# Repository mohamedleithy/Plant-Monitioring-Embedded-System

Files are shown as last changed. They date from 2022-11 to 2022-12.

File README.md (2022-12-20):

# Plant-Monitioring-Embedded-System

## Table of contents

* [Introduction ](https://github.com/mohamedleithy/Plant-Monitioring-Embedded-System#-introduction)
* [Background and Motivation](https://github.com/mohamedleithy/Plant-Monitioring-Embedded-System#Background-and-Motivation)
* [Problem Statement](https://github.com/mohamedleithy/Plant-Monitioring-Embedded-System#problem-statement)
* [Solution](https://github.com/mohamedleithy/Plant-Monitioring-Embedded-System#solution)
* [Features](https://github.com/mohamedleithy/Plant-Monitioring-Embedded-System#features)
* [Scale of the project](https://github.com/mohamedleithy/Plant-Monitioring-Embedded-System#scale-of-the-project)
* [Architecture](https://github.com/mohamedleithy/Plant-Monitioring-Embedded-System#architecture)
* [Iterations](https://github.com/mohamedleithy/Plant-Monitioring-Embedded-System#Iterations)
* [Benefits](https://github.com/mohamedleithy/Plant-Monitioring-Embedded-System#benefits)
* [Dashboard](https://github.com/mohamedleithy/Plant-Monitioring-Embedded-System#dashboard)
* [Conclusion and Future Work](https://github.com/mohamedleithy/Plant-Monitioring-Embedded-System#Conclusion-and-Future-Work)
* [Demo video](https://github.com/mohamedleithy/Plant-Monitioring-Embedded-System#Demo-video)
* [Authors](https://github.com/mohamedleithy/Plant-Monitioring-Embedded-System#authors)
* [Limitations](https://github.com/mohamedleithy/Plant-Monitioring-Embedded-System#limitations)
* [Supervisor](https://github.com/mohamedleithy/Plant-Monitioring-Embedded-System#supervisor)

# Introduction

Plant monitoring is a fundamental component of agriculture industries since it allows for controlling the growth of plants for the best possible output. Automating the process of plant monitoring and managing the environmental factors will ease the complexity of such process and will influence the growth of the plant and, consequently, its output. In this proposal a plant monitoring system is presented to provide feedback for the user on a web app. The proposal includes a detailed description of the problem, architecture of the system and the components used.

# Background and Motivation

After skimming through the past projects, we found a past project that used sensors to record the temperature,humidty and soil mositure. We then decided we can improve on this project by actuating on these sensor readings in negative feedback loop. By doing so, we would provide a given plant with the optimial needed conditions (soil mositure) and automate the process of watering. 

# Problem Statement

We are addressing two problems:

* The water waste introduced by the classical agricultural techniques.
* The high running cost of the agricultural sites workers.

# Solution

Designing an embedded system with a negative feedback loop to efficiently monitor and control agricultural sites. The system will monitor the environment by deploying sensors that keep track of the temperature, humidity, and soil moisture level, to regulate the soil water level using an electronically controlled water valve. An online dashboard will be integrated into the system to report updates on the agricultural site.

# Requirmenets and Features

* The user will be able to select his/her plant type through the web interface, and the soil moisture level is specified accordingly
* The system will be able to monitor the temperature and soil moisture level.
* The system will be able to control the water level in the soil.
* The system will be able to modify the soil moisture level, based on the temprature. 
* The system will be able to report updates on the environment to the user.

# Scale of the project

* The system will be able to monitor indoor plants on a small scale, prototype is made on two average sized plant pots.

# Architecture

## Software architecture design

For the STM board:
We designed our embedded system to used FreeRTOS to coordinate its different tasks. The use of FreeRTOS was essential to allow parallel execution of the tasks in a real-time fashion. Moreover, the use of interrupts opened the door for handling aperiodic tasks in the system, and data racing conditions were handled using semaphores. 

For the raspberry pi pico:
Here we used a multithreaded architecture to allow the blocking of synchronous receiving and sending of the server. The python _thread library was used to generate a couple of threads that separately handle the sockets operations and the UART communication with the STM board.

## Hardware architecture design

### Block Diagram

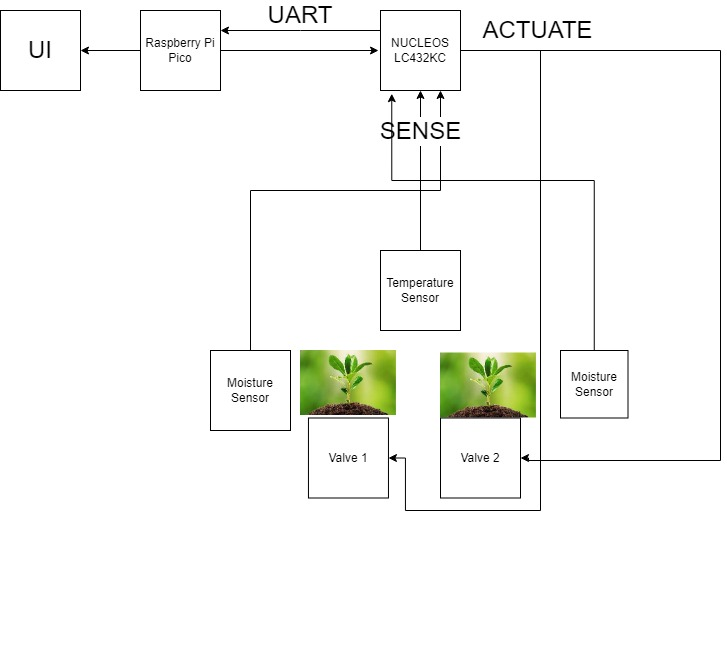
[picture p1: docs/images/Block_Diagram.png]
Block Diagram


### System Components

 * NUCLEO LC432K 
 * Raspberry pi pico 
 * Water Valve
 * Humidity Sensor
 * Temperature Sensor (DS3231 RTC)
 * Mositure Sensor 

#### NUCLEO LC432K
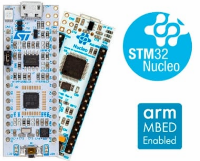
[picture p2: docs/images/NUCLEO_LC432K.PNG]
NUCLEO LC432K


#### Raspberry pi pico

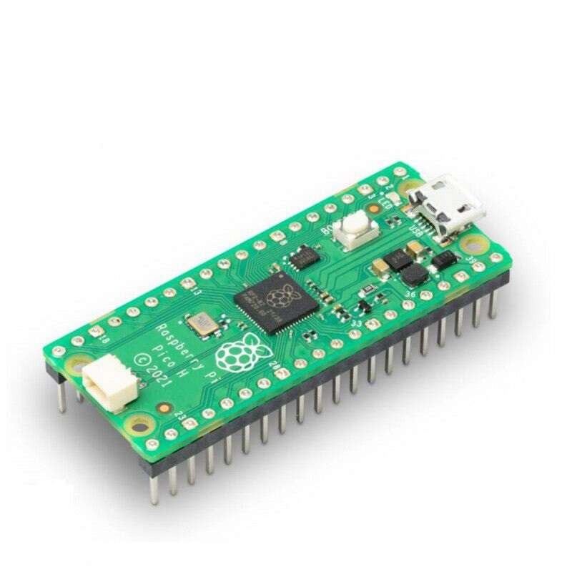
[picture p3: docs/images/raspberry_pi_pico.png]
ESP32


#### Water Valve

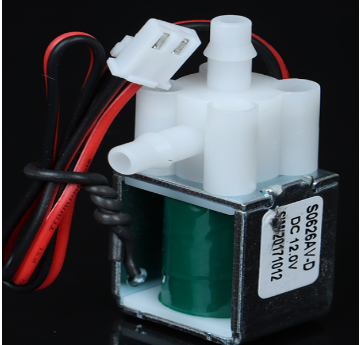
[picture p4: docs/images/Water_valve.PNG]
Water Valve


#### Relay

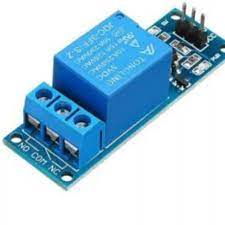
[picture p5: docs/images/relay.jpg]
Relay


#### Temperature Sensor

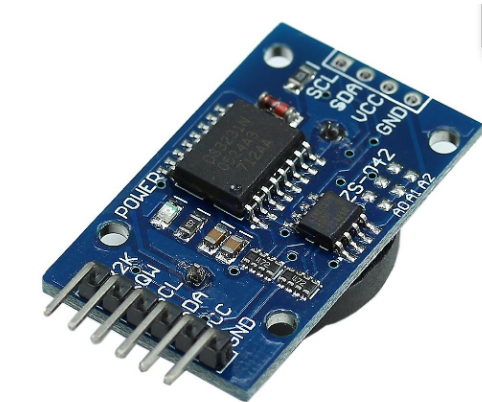
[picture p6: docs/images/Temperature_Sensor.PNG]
Temperature Sensor


#### Mositure Sensor

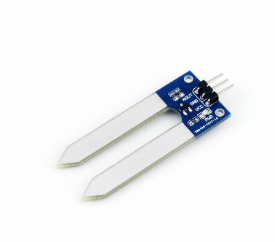
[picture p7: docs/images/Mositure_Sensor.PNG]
Mositure Sensor


### Connections:

* Deploy the STM board on the breadboard
* Deploy the Raspberry Pi Pico board on the breadboard
* Connect the two microcontrollers together via UART serial connection
* Connect the temprature sensor to the STM board using i2c synchronous connection
* Connect the 2 moisture sensor to the STM board using built in ADC on two seperate channels
* Connect each 12V supply to relay, connect relay output to the water valves
* Connect GPIO Pins to designated relay.

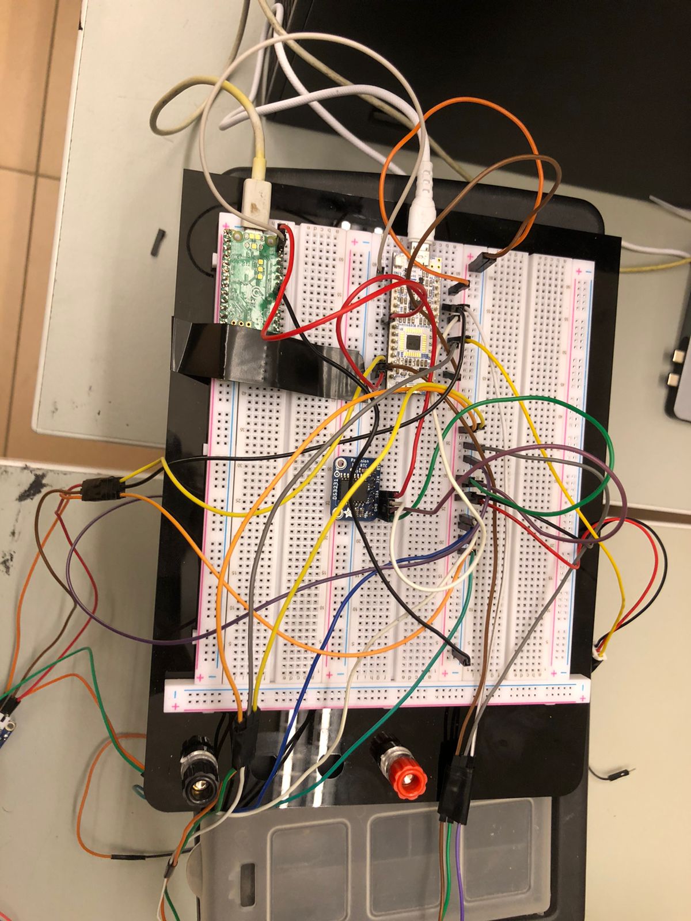
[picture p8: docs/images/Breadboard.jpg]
Breadboard Image


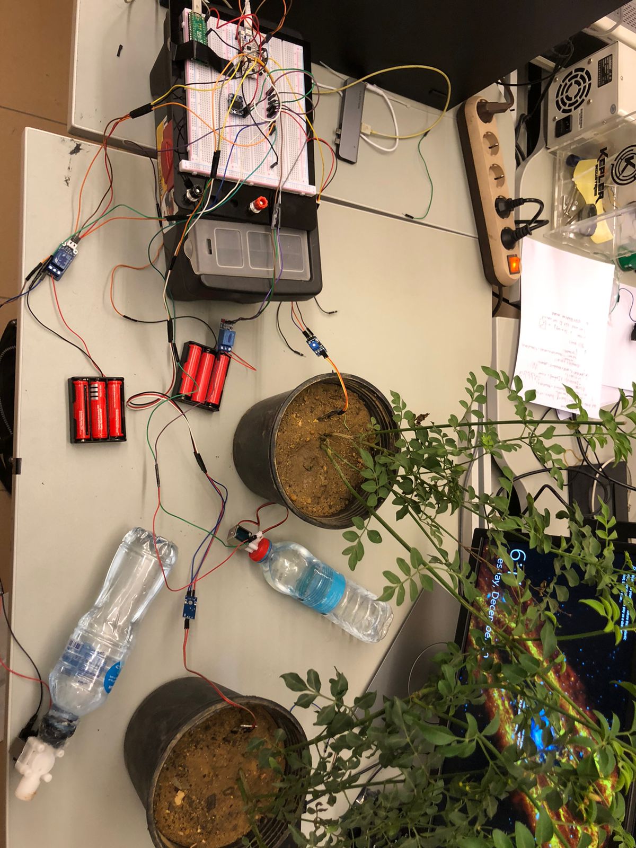
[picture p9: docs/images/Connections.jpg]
Connection Image


# Iterations

## First phase

Deployed STM and connected it to soil moisture and temperature sensor. 
Deployed ESP32 and connected it to humidty sensor.
Displayed Readings on Dashboard via Build-in Arudino APIs.

## Second phase

Removed ESP32 and deployed Raspberry Pico Pi.
Implemented User Interface via HTML, and intergrated front-end with Raspberry Pico Pi python back-end.

# Benefits

## Automation 
This embedded system would automate the process of watering plants, thus removing the need for human intervention on a daily basis resulting in error-free result in comparison to human labor, increasing consistency and reducing costs. 
## Real Time Display
With the use of the dashboard the user would be able to view the the real-time temperature, humidity and moisture directly through his/her phone/Desktop and get notified through telegram mobile application when any of the parameters approaches its threshold. 
## Set Optimal Conditions 
Given the monitored parameters, the system is able to water the plant and provide it with its optimal ecosystem that are predefined for a certain plant species to allow maximizing the plants’ growth and yield.

# Conlusion and Future Work

## Conclusion

it can be concluded that the system implemented successfully reads the soil moisture of plants and waters the plants accordingly. This system can be an effective solution for maintaining optimal soil moisture levels for plants, which is important for their health and growth. It can potentially save time and effort for gardeners and farmers by automating the watering process, and it may also help to conserve water by avoiding over-watering or under-watering. Overall, the implementation of this system appears to be a useful tool for the care and maintenance of plants.

## Future Work
* Adding additional sensors: The system could be enhanced with additional sensors to monitor other factors that may impact plant growth and health, such as light levels or nutrient levels in the soil.
* Expanding the watering capabilities: The system could be designed to support larger water bottles or to incorporate additional watering methods, such as a drip irrigation system or a spray system. This could allow the system to water plants more efficiently and effectively, particularly for larger grow areas or for plants with different watering needs.
* Improving the water bottle filling process: The system could be enhanced to make the process of filling the water bottles more efficient and convenient, potentially through the use of a water pump or other automation techniques.

# Dashboard

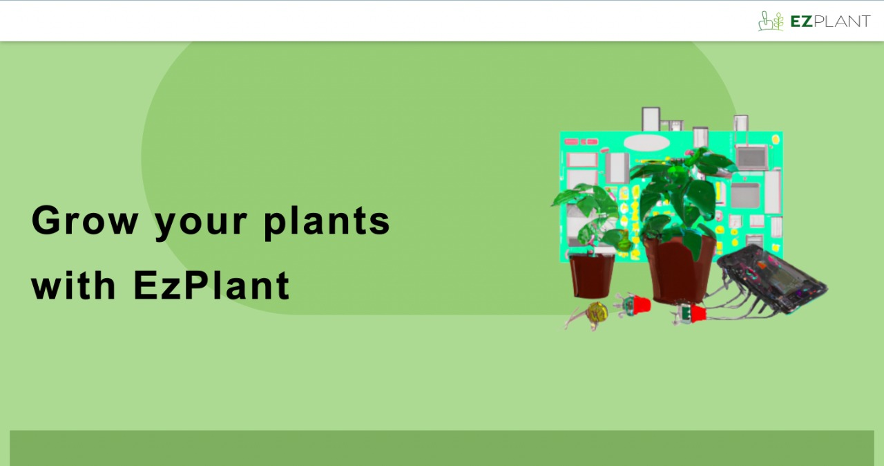
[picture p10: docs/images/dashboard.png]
Dashboard Image


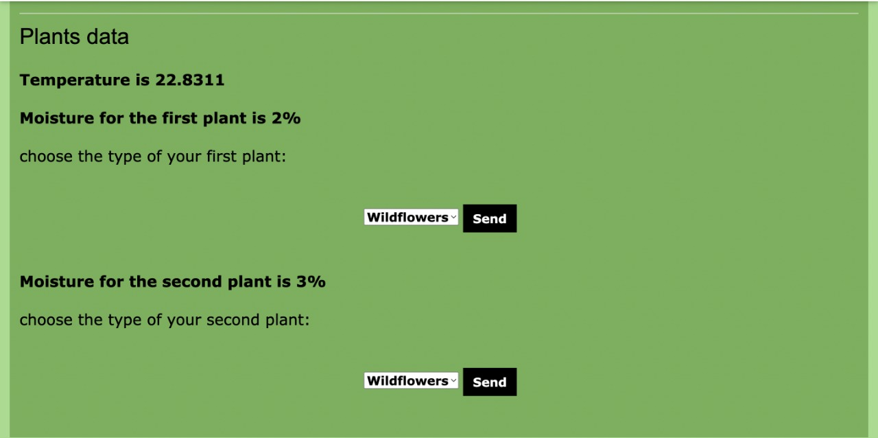
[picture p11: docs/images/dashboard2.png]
Dashboard Image 2


# Project Progress and Demo video

The system is now able to monitor the soil moisture level in two average sized plant pots, along with the temperature, and accordingly switch on/off the relay that controls the water solenoids attached to the water source. 

[Demo video link](https://drive.google.com/file/d/1defMuau6kGnW1_lsAHdz8Dkl8jO6r3im/view?usp=sharing)

# Limitations

* Our system handles no more than 6 pots.
* Distance limitation because the digital signal received by the ADC will catch a lot of noise
* The system is very expensive due to the cost of the components compared to the scale
* The system does not handle failures
    * Over-watering 
    * Does not troubleshoot technical issues in sensors
    * Force quit the system when a technical issue happens

# 3D Model of the system

* Base of the model
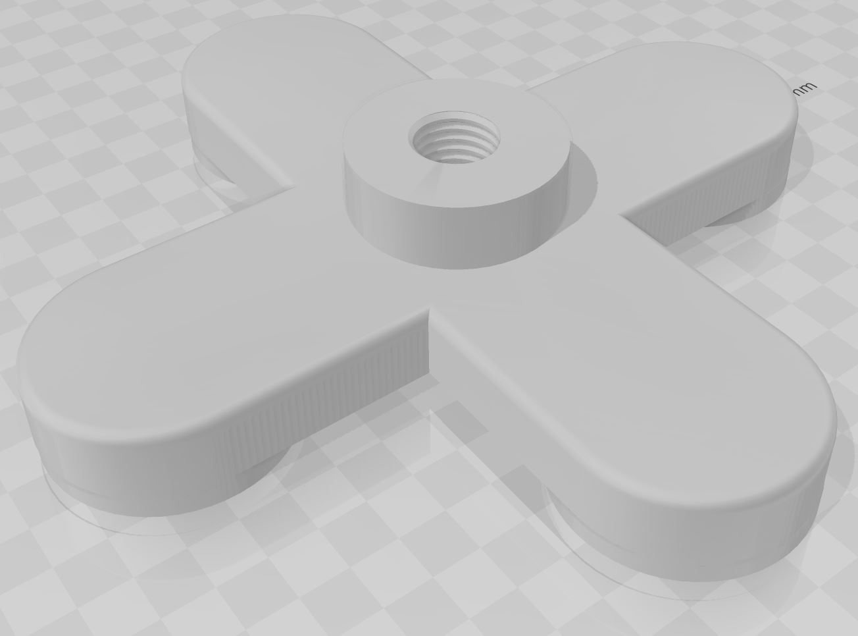
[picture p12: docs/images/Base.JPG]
Base of the model


* Cap of the model
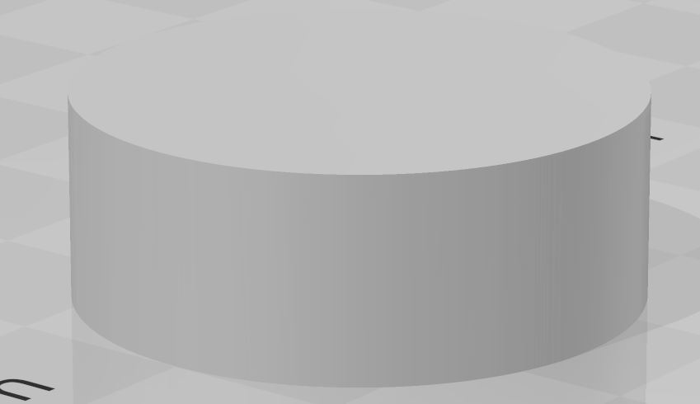
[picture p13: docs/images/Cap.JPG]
Cap of the model


* rod

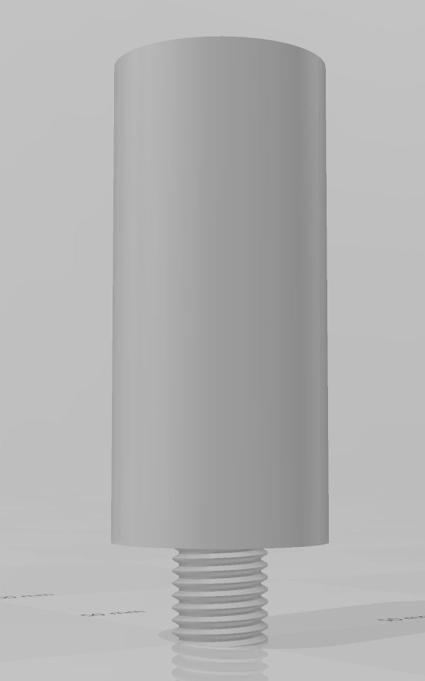
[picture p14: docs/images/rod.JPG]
rod


* Bottle

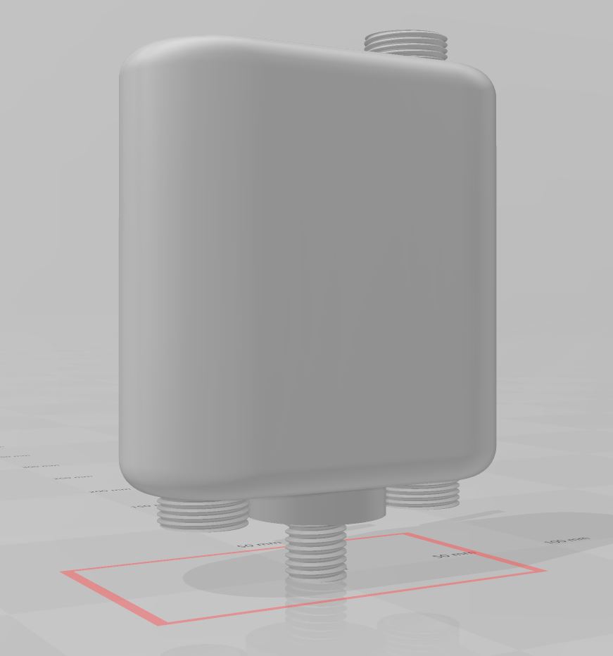
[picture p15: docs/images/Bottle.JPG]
Bottle


* Whole Model

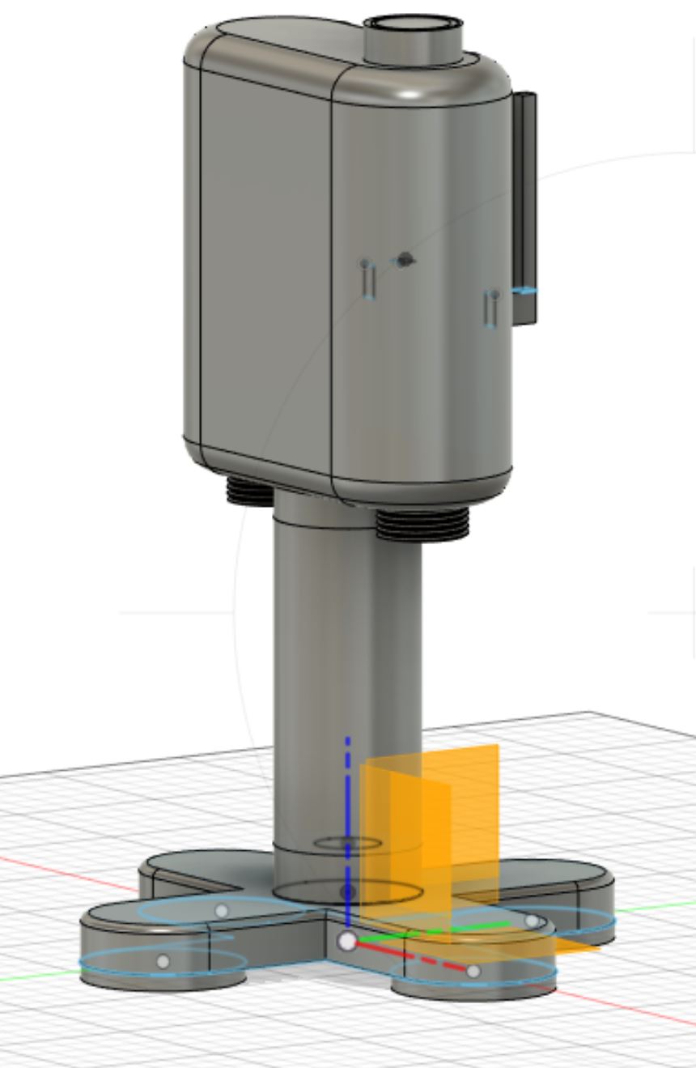
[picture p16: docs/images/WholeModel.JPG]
whole model


* Real image of the model (not printed properly)

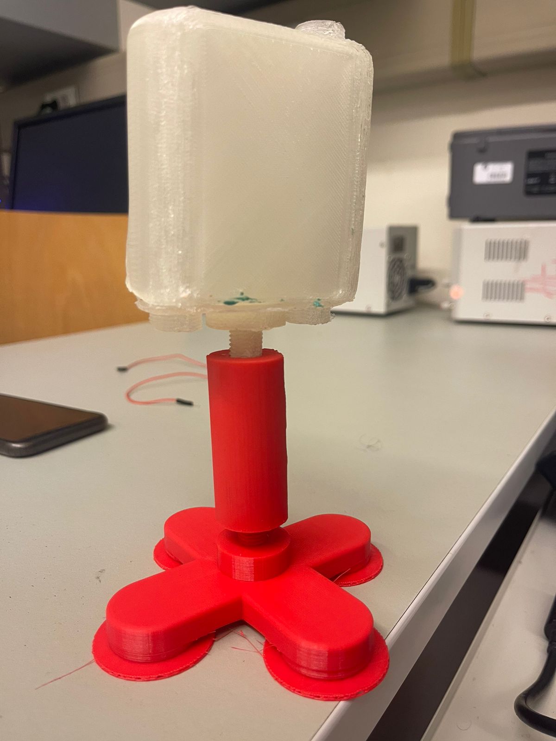
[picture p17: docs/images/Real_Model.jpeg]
Real model


* The model is basically consists of 4 parts:
    * The base
    * The cap
    * The rod
    * The bottle
* Each one of them is 3D printed and assembled together to form the final model. The base is assembled with the rods and the bottle is assembled with the cap and the rod. The bottle is then inserted into the base and the cap is inserted into the bottle.
The two opeenings in the bottom is responsible for the water to flow out of the bottle and the one opening in the top is responsible for the water to flow into the bottle for filling the bottle up.

# Authors

* [Mohamed Nasr](https://github.com/mnassr1658)
* [Mohamed Eleithy](https://github.com/mohamedleithy)
* [Abdullah Nashat](https://github.com/n42at)
* [Youssef Kandil](https://github.com/kanndil)

# Supervisor

* [Mohamed Shalan](https://github.com/shalan)

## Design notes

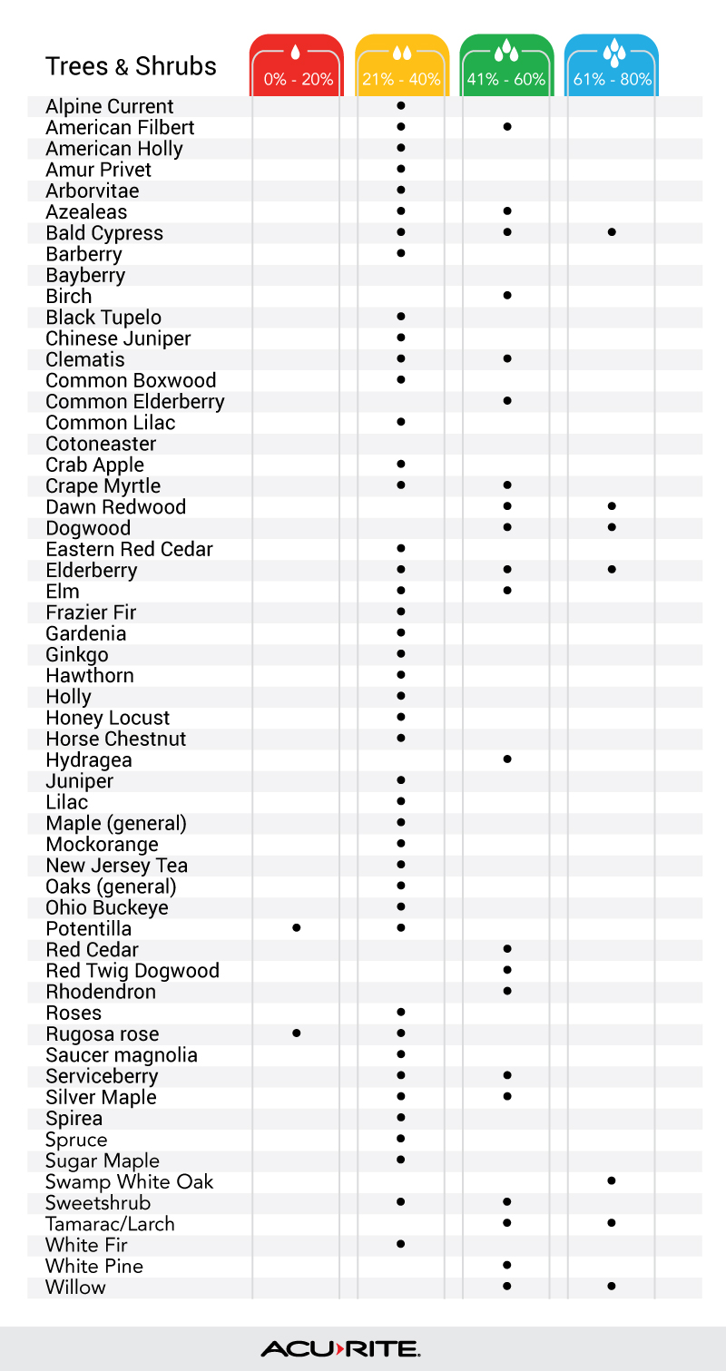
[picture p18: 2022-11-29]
docs/images/Trees&Shrubs.png

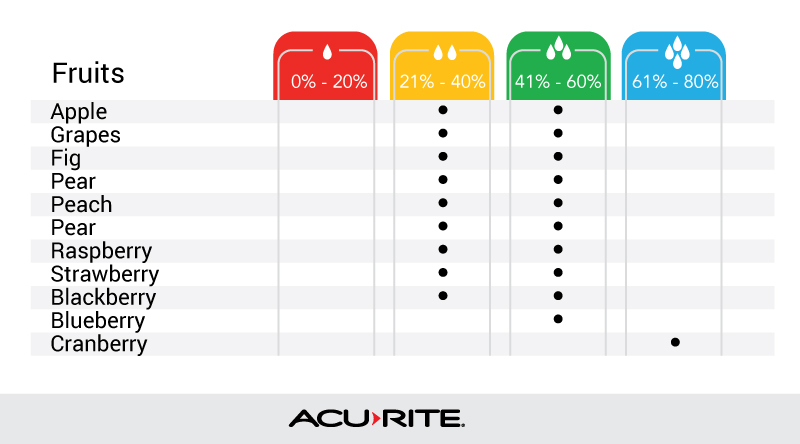
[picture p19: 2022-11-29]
docs/images/fruits.png

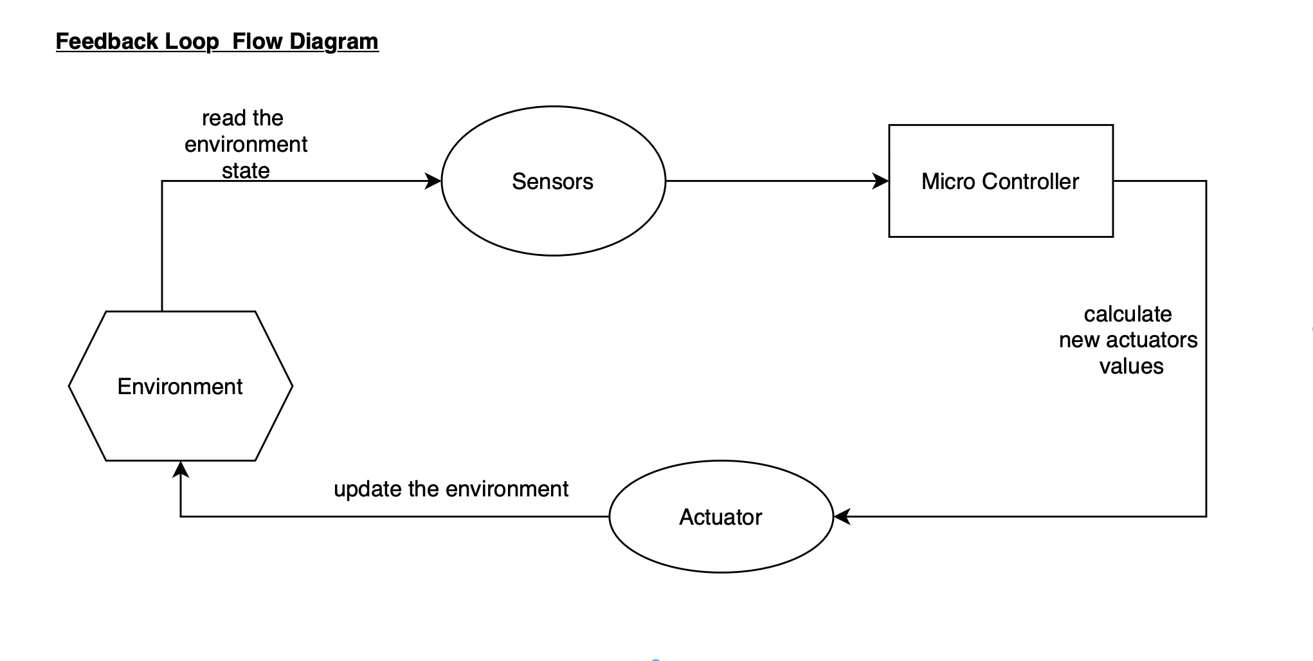
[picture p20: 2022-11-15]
docs/images/FeedbackLoop.png

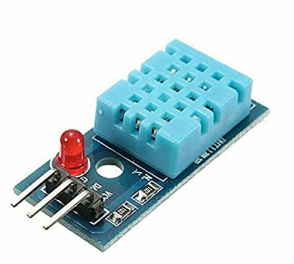
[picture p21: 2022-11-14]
docs/images/Humidity_Sensor.PNG

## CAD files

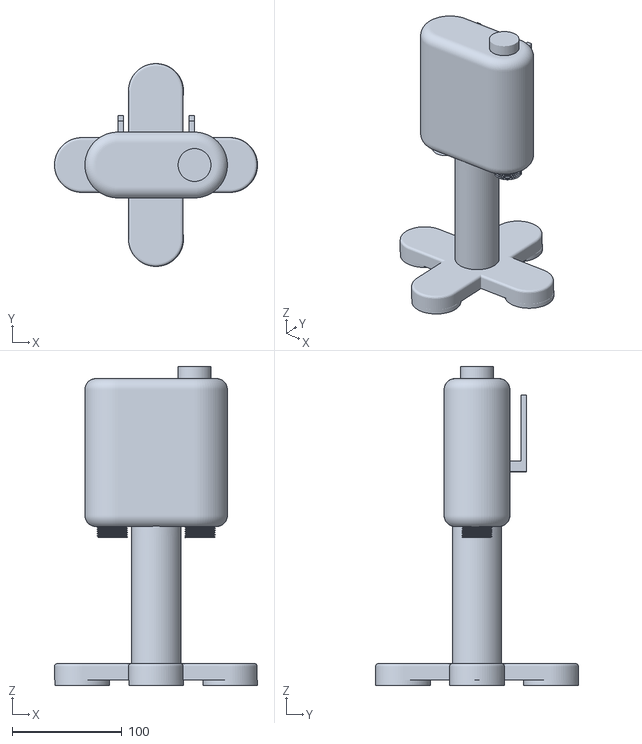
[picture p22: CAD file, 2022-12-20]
3DModeling/Whole Model.stl
185.3 x 185.0 x 291.0

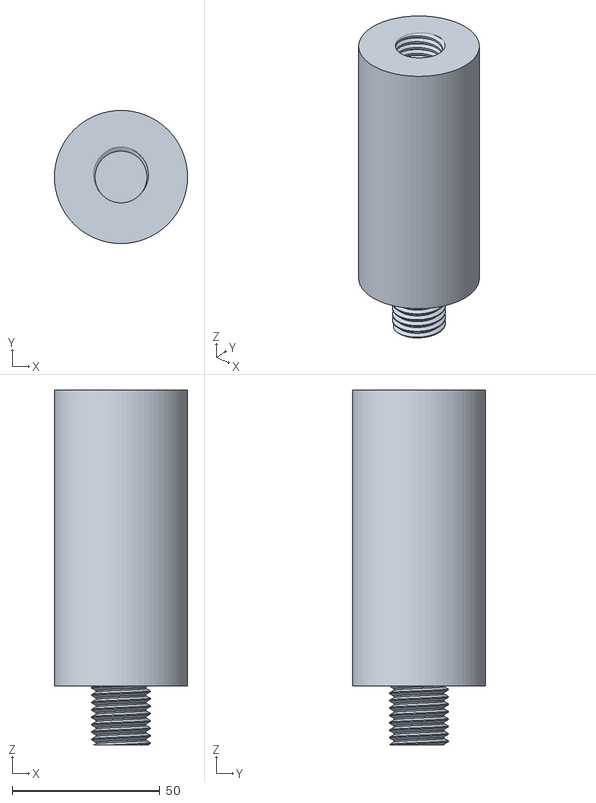
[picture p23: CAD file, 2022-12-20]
3DModeling/Rod.stl
45.0 x 45.0 x 120.0

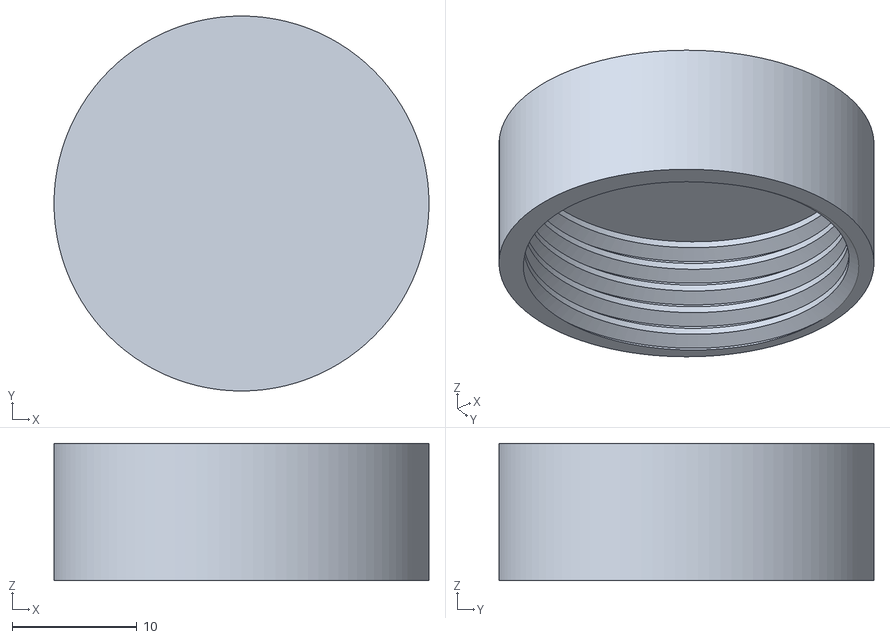
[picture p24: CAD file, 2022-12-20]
3DModeling/Cap.stl
30.0 x 30.0 x 11.0

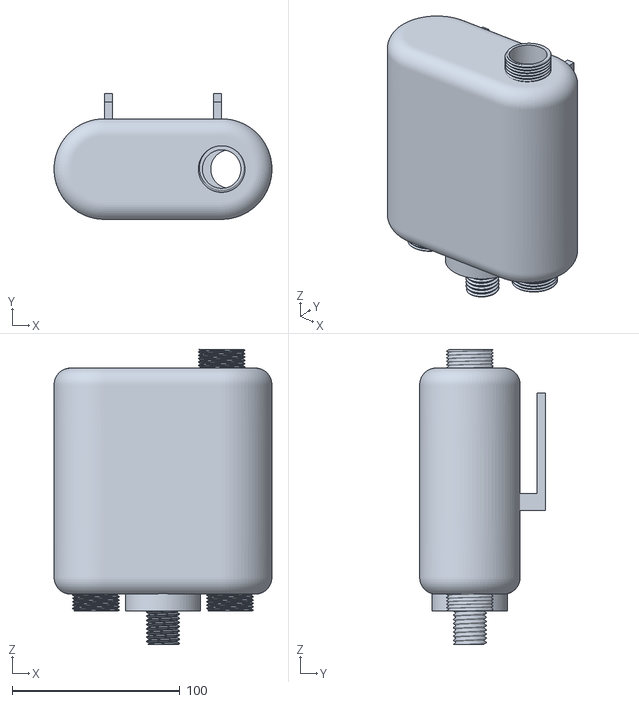
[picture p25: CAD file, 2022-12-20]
3DModeling/Bottle.stl
130.0 x 75.0 x 176.0

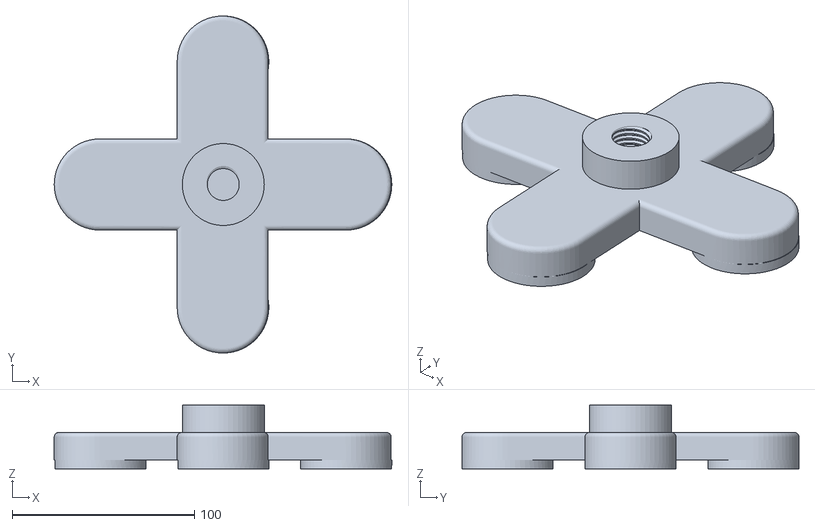
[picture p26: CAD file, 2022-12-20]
3DModeling/Base.stl
185.3 x 185.0 x 35.0

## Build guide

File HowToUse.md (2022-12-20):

# How to use 

## STM32 
* Check the pin configurations and connect the needed wires based on the connection section in the readme file and the CubeMX configuration project
* Build the source code using Keil software 
* Load to the STM MicroController

## Raspberry PI Pico
* Open the Thonny IDE to interface with the Raspberry PI pico 
* Open server.py on Thonny 
* Configure the WIFI SSID and Password 
* Load the code onto the MicroController

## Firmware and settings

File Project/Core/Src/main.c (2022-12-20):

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
/* Includes ------------------------------------------------------------------*/
#include "main.h"
#include "cmsis_os.h"

/* USER CODE BEGIN Includes */
#include <stdio.h>
#include "FreeRTOS.h"
#include "queue.h"
#include "task.h"
#include "semphr.h"
/* USER CODE END Includes */

/* USER CODE BEGIN PM */

extern float moisture_perc;
extern float moisture_perc2;
extern int adcflag;
/* USER CODE END PM */

ADC_HandleTypeDef hadc1;

I2C_HandleTypeDef hi2c3;

UART_HandleTypeDef huart1;
UART_HandleTypeDef huart2;

/* Definitions for defaultTask */
osThreadId_t defaultTaskHandle;
const osThreadAttr_t defaultTask_attributes = {
  .name = "defaultTask",
  .stack_size = 128 * 4,
  .priority = (osPriority_t) osPriorityNormal,
};
/* Definitions for SensorsTask */
osThreadId_t SensorsTaskHandle;
const osThreadAttr_t SensorsTask_attributes = {
  .name = "SensorsTask",
  .stack_size = 128 * 4,
  .priority = (osPriority_t) osPriorityLow,
};
/* Definitions for UartCommunicati */
osThreadId_t UartCommunicatiHandle;
const osThreadAttr_t UartCommunicati_attributes = {
  .name = "UartCommunicati",
  .stack_size = 128 * 4,
  .priority = (osPriority_t) osPriorityLow,
};
/* Definitions for Calculate */
osThreadId_t CalculateHandle;
const osThreadAttr_t Calculate_attributes = {
  .name = "Calculate",
  .stack_size = 128 * 4,
  .priority = (osPriority_t) osPriorityLow,
};
/* Definitions for Calculate2 */
osThreadId_t Calculate2Handle;
const osThreadAttr_t Calculate2_attributes = {
  .name = "Calculate2",
  .stack_size = 128 * 4,
  .priority = (osPriority_t) osPriorityLow,
};
/* Definitions for UartCom2 */
osThreadId_t UartCom2Handle;
const osThreadAttr_t UartCom2_attributes = {
  .name = "UartCom2",
  .stack_size = 128 * 4,
  .priority = (osPriority_t) osPriorityLow,
};
/* Definitions for myBinarySem01 */
osSemaphoreId_t myBinarySem01Handle;
const osSemaphoreAttr_t myBinarySem01_attributes = {
  .name = "myBinarySem01"
};
/* USER CODE BEGIN PV */


uint8_t ctlbuf[2],statbuf[2], tempupsend[1],tempdownsend[1], tempuprec[1],tempdownrec[1];
uint8_t tempvalue;
float tempfr, tempfinal;
uint8_t humidity,temp1; 
uint8_t uartBuf [100], uartBuf1 [100] = {0};
char uartBuf2[100] = {0}, uartBuf3[100] = {0}, uartBuf4[100] = {0};
float moistureLimit =60.0;
float moistureLimit2 =60.0;
uint8_t data[2] = {0};

/* USER CODE END PV */

void SystemClock_Config(void);
static void MX_GPIO_Init(void);
static void MX_USART2_UART_Init(void);
static void MX_ADC1_Init(void);
static void MX_I2C3_Init(void);
static void MX_USART1_UART_Init(void);
void StartDefaultTask(void *argument);
void StartTask02(void *argument);
void StartTask03(void *argument);
void StartTask04(void *argument);
void StartTask05(void *argument);
void StartTask06(void *argument);

/**
  * @brief  The application entry point.
  * @retval int
  */
int main(void)
{
  /* MCU Configuration--------------------------------------------------------*/

  /* Reset of all peripherals, Initializes the Flash interface and the Systick. */
  HAL_Init();

  /* Configure the system clock */
  SystemClock_Config();

  /* Initialize all configured peripherals */
  MX_GPIO_Init();
  MX_USART2_UART_Init();
  MX_ADC1_Init();
  MX_I2C3_Init();
  MX_USART1_UART_Init();
  /* USER CODE BEGIN 2 */
  __HAL_UART_ENABLE_IT(&huart1,UART_IT_RXNE);
  ctlbuf[0] = 0x0E;
	ctlbuf[1] = 0x3C;
 
  HAL_I2C_Master_Transmit(&hi2c3, 0xD0, ctlbuf, 2, 10);

	statbuf[0] = 0x0F;
	statbuf[1] = 0x88;
 
	HAL_I2C_Master_Transmit(&hi2c3, 0xD0, statbuf, 2, 10);
	// send to tempupper upperbyte register /*Integer Part*/
  tempupsend[0] = 0x11; // address of the register // reference page: DS page 15
  HAL_I2C_Master_Transmit(&hi2c3, 0xD0, tempupsend, 2, 10);
  // send to tempupper lowerbyte register /*Fractional Part*/
  tempdownsend[0] = 0x12; // address of the register // reference page: DS page 15
  HAL_I2C_Master_Transmit(&hi2c3, 0xD0, tempdownsend, 2, 10);
  /* USER CODE END 2 */

  /* Init scheduler */
  osKernelInitialize();

  /* USER CODE BEGIN RTOS_MUTEX */
  /* add mutexes, ... */
  /* USER CODE END RTOS_MUTEX */

  /* Create the semaphores(s) */
  /* creation of myBinarySem01 */
  myBinarySem01Handle = osSemaphoreNew(1, 1, &myBinarySem01_attributes);

  /* USER CODE BEGIN RTOS_SEMAPHORES */
  /* add semaphores, ... */
  /* USER CODE END RTOS_SEMAPHORES */

  /* USER CODE BEGIN RTOS_TIMERS */
  /* start timers, add new ones, ... */
  /* USER CODE END RTOS_TIMERS */

  /* USER CODE BEGIN RTOS_QUEUES */
  /* add queues, ... */
  /* USER CODE END RTOS_QUEUES */

  /* Create the thread(s) */
  /* creation of defaultTask */
  defaultTaskHandle = osThreadNew(StartDefaultTask, NULL, &defaultTask_attributes);

  /* creation of SensorsTask */
  SensorsTaskHandle = osThreadNew(StartTask02, NULL, &SensorsTask_attributes);

  /* creation of UartCommunicati */
  UartCommunicatiHandle = osThreadNew(StartTask03, NULL, &UartCommunicati_attributes);

  /* creation of Calculate */
  CalculateHandle = osThreadNew(StartTask04, NULL, &Calculate_attributes);

  /* creation of Calculate2 */
  Calculate2Handle = osThreadNew(StartTask05, NULL, &Calculate2_attributes);

  /* creation of UartCom2 */
  UartCom2Handle = osThreadNew(StartTask06, NULL, &UartCom2_attributes);

  /* USER CODE BEGIN RTOS_THREADS */
  /* add threads, ... */
  /* USER CODE END RTOS_THREADS */

  /* USER CODE BEGIN RTOS_EVENTS */
  /* add events, ... */
  /* USER CODE END RTOS_EVENTS */

  /* Start scheduler */
  osKernelStart();

  /* We should never get here as control is now taken by the scheduler */
  /* Infinite loop */
  /* USER CODE BEGIN WHILE */
	
  while (1)
  {
    /* USER CODE END WHILE */

    /* USER CODE BEGIN 3 */


  }
  /* USER CODE END 3 */
}

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
/* USER CODE BEGIN Header_StartDefaultTask */
/**
  * @brief  Function implementing the defaultTask thread.
  * @param  argument: Not used
  * @retval None
  */
/* USER CODE END Header_StartDefaultTask */
void StartDefaultTask(void *argument)
{
  /* USER CODE BEGIN 5 */
  /* Infinite loop */
		moistureLimit =60.0;
		moistureLimit2 =60.0;
  for(;;)
  { 			
		
		int moistureLimitSeason =moistureLimit;
		int	moistureLimitSeason2 = moistureLimit2;
			if (tempfinal>23){
				moistureLimitSeason  +=10;
				moistureLimitSeason2 +=10;
			}
			
			
			if(moisture_perc<= moistureLimitSeason){
				HAL_GPIO_WritePin(GPIOB, GPIO_PIN_5, 1);
			}else{
				HAL_GPIO_WritePin(GPIOB, GPIO_PIN_5, 0);
			}
			if(moisture_perc2<= moistureLimitSeason2){
				HAL_GPIO_WritePin(GPIOA, GPIO_PIN_11, 1);
			}else{
				HAL_GPIO_WritePin(GPIOA, GPIO_PIN_11, 0);
			}		
			
    osDelay(1);
 
  }
  /* USER CODE END 5 */
}

/* USER CODE BEGIN Header_StartTask02 */
/**
* @brief Function implementing the SensorsTask thread.
* @param argument: Not used
* @retval None
*/
/* USER CODE END Header_StartTask02 */
void StartTask02(void *argument)
{
  /* USER CODE BEGIN StartTask02 */
  /* Infinite loop */
	adcflag=1;
  for(;;)
  {
		//send tempupper byte register address 11h to read from
		HAL_I2C_Master_Transmit(&hi2c3, 0xD0, tempupsend, 1, 10);
		//read data of register 11h to tempUpperByte[1]
		HAL_I2C_Master_Receive(&hi2c3, 0xD1, tempuprec, 1, 10);
		tempvalue = tempuprec[0];

		//send tempupper byte register address 11h to read from
		HAL_I2C_Master_Transmit(&hi2c3, 0xD0, tempdownsend, 1, 10);
		//read data of register 11h to tempUpperByte[1]
		/* Shift left by 6 since in the templowerbyte register, we are interested
		* in the least 2 significant bits as the fractional part
		* hence shift right by 6
		*/
		HAL_I2C_Master_Receive(&hi2c3, 0xD1, tempdownrec, 1, 10);
		tempfr = (tempdownrec[0] >> 6)*0.25; // 0.25 resolution

		tempfinal = tempvalue + tempfr;
		sprintf((char *)uartBuf, "Temperature: %f \r\n", tempfinal);
		
		
		//prepare UART output
		HAL_Delay(1000);
		HAL_ADC_Start_IT(&hadc1);
		
		HAL_Delay(50);
		

		sprintf(uartBuf3,"<%d %d %d>",(int)moisture_perc,(int)moisture_perc2, (int)tempfinal);

  }
  /* USER CODE END StartTask02 */
}

/* USER CODE BEGIN Header_StartTask03 */
/**
* @brief Function implementing the UartCommunicati thread.
* @param argument: Not used
* @retval None
*/
/* USER CODE END Header_StartTask03 */
void StartTask03(void *argument)
{
  /* USER CODE BEGIN StartTask03 */
  /* Infinite loop */
  for(;;)
  {
		
			HAL_UART_Transmit(&huart1,(uint8_t *) uartBuf3,10, HAL_MAX_DELAY);
			// HAL_UART_Transmit(&huart1,(uint8_t *) uartBuf4,40, HAL_MAX_DELAY);
			for (int i = 0 ; i<10 ; i++){
				HAL_Delay(5);
			}

  
}
  /* USER CODE END StartTask03 */
}

/* USER CODE BEGIN Header_StartTask04 */
/**
* @brief Function implementing the Calculate thread.
* @param argument: Not used
* @retval None
*/
/* USER CODE END Header_StartTask04 */
void StartTask04(void *argument)
{
  /* USER CODE BEGIN StartTask04 */
  /* Infinite loop */


  for(;;)
  {
	
		
		if(xSemaphoreTake(myBinarySem01Handle,  999999)) {

				//recieve
				HAL_UART_Receive(&huart1, data, sizeof(data), HAL_MAX_DELAY);
				//enable UART recieve
				__HAL_UART_ENABLE_IT(&huart1, UART_IT_RXNE);
 
				if (data[0]=='1'){
					moistureLimit= (data[1]-48)*10;
					
				}else{
					moistureLimit2= (data[1]-48)*10;
				}

		}
  }
  /* USER CODE END StartTask04 */
}

/* USER CODE BEGIN Header_StartTask05 */
/**
* @brief Function implementing the Calculate2 thread.
* @param argument: Not used
* @retval None
*/
/* USER CODE END Header_StartTask05 */
void StartTask05(void *argument)
{
  /* USER CODE BEGIN StartTask05 */
  /* Infinite loop */
  for(;;)
  {
		
    osDelay(1);
  }
  /* USER CODE END StartTask05 */
}

/* USER CODE BEGIN Header_StartTask06 */
/**
* @brief Function implementing the UartCom2 thread.
* @param argument: Not used
* @retval None
*/
/* USER CODE END Header_StartTask06 */
void StartTask06(void *argument)
{
  /* USER CODE BEGIN StartTask06 */
  /* Infinite loop */
  for(;;)
  {	
    osDelay(1);
  }
  /* USER CODE END StartTask06 */
}

/**
  * @brief  This function is executed in case of error occurrence.
  * @retval None
  */
void Error_Handler(void)
{
  /* USER CODE BEGIN Error_Handler_Debug */
  /* User can add his own implementation to report the HAL error return state */
  __disable_irq();
  while (1)
  {
  }
  /* USER CODE END Error_Handler_Debug */
}

#ifdef  USE_FULL_ASSERT
/**
  * @brief  Reports the name of the source file and the source line number
  *         where the assert_param error has occurred.
  * @param  file: pointer to the source file name
  * @param  line: assert_param error line source number
  * @retval None
  */
void assert_failed(uint8_t *file, uint32_t line)
{
  /* USER CODE BEGIN 6 */
  /* User can add his own implementation to report the file name and line number,
     ex: printf("Wrong parameters value: file %s on line %d\r\n", file, line) */
  /* USER CODE END 6 */
}
#endif /* USE_FULL_ASSERT */

/************************ (C) COPYRIGHT STMicroelectronics *****END OF FILE****/

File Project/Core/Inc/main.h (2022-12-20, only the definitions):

#define MCO_Pin GPIO_PIN_0
#define MCO_GPIO_Port GPIOA
#define SWDIO_Pin GPIO_PIN_13
#define SWDIO_GPIO_Port GPIOA
#define SWCLK_Pin GPIO_PIN_14
#define SWCLK_GPIO_Port GPIOA
#define LD3_Pin GPIO_PIN_3
#define LD3_GPIO_Port GPIOB

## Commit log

2022-11-14 added model to temperature Sensor
2022-11-15 adding flow diagram
2022-11-15 adding flow diagram png
2022-11-29 Receiving UART from STM
2022-11-29 initializing DHT and testing sensor
2022-11-29 adding temprature sensor on stm
2022-11-29 Added ADC for moisture, and documentation
2022-12-20 modefied interrupt and tasks
2022-12-20 Adding 3D models Files
    [Base.stl, Bottle.stl, Cap.stl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]

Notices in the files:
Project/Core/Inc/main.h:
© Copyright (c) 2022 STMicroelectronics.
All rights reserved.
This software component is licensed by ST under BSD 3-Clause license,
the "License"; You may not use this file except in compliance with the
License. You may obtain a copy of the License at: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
